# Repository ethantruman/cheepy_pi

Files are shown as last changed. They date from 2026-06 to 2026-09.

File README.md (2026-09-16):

# cheepy_pi

A budget-friendly, fully opensource DIY mini Cyberdeck powered by Raspberry Pi Model B, featuring a custom BQ25895+TPS61236P UPS, 3 cheap ST7789 display and audio system.

<p align="center">
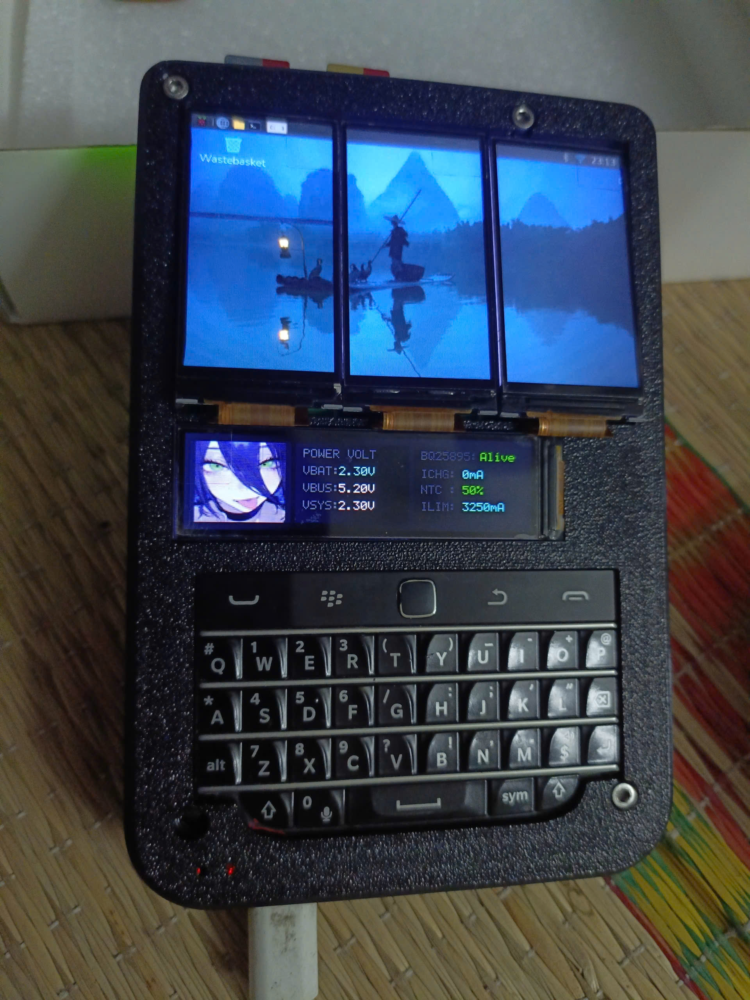
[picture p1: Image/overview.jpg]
Rear 3D View
  
  &nbsp;&nbsp;&nbsp;&nbsp;
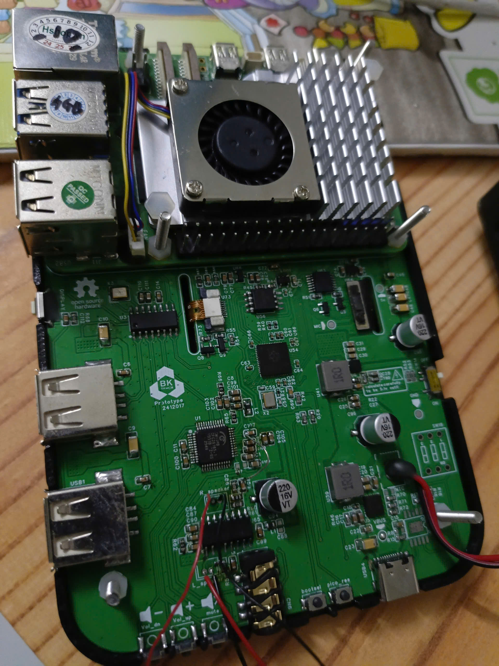
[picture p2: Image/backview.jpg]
Second View
  
</p>

## 🎬 Video Demo
https://www.instagram.com/reel/DcwldvmTygn/?stkn=MTkzajRhMjB0NHE0aw== <br>

https://www.youtube.com/shorts/QTE_7KOaZrw <br>

https://youtube.com/shorts/9MWYKX_wWpU?si=94ie98PXgPygaU7K

## Architecture
<p align="center">
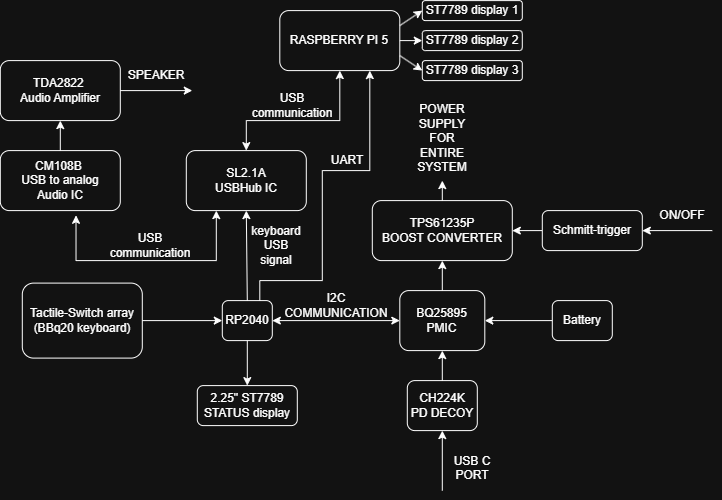
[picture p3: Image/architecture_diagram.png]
  
</p>

## Features
* **Processor:** Powered by Raspberry Pi Model B.
* **Power System:** Custom UPS utilizing BQ25895 + TPS61236P. It integrates a **CH220K** fast-charging sink controller at the input to negotiate up to a **12V input voltage** from Type-C PD charger, significantly boosting input power and enabling faster charging/stable high-load operation when plugged in.
* **Display System:** 
  * Triple (3x) low-cost ST7789 1.9" main screens.
  * An extra 2.25" ST7789 display dedicated to monitoring and displaying real-time battery status, independently managed by an onboard RP2040 microcontroller.
* **Input:** Integrated classic Blackberry Q20 keyboard, also driven and managed by the RP2040 to act as a custom USB HID device.

* **Audio:** Integrated audio system.
  
##  Current Status & Testing
* **Hardware Status:** The project is currently in the prototype stage. I am waiting for the PCBs and components to arrive for soldering, hardware debugging, and error verification. Updates will be posted as soon as testing is complete!
<p align="center">
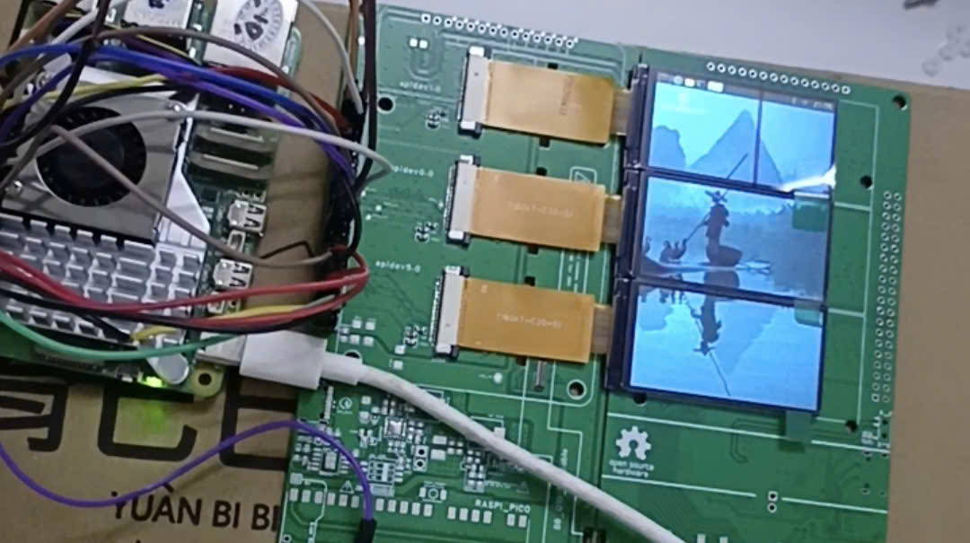
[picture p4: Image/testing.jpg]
Testing
  
</p>

* **Software/Driver Notice:** 
  The current driver for the triple (3x) ST7789 display system **only supports the latest Raspberry Pi OS** and other Linux distributions utilizing the ́**Wayland** display server protocol. Traditional X11/Xorg environments are not supported.
  
* **Update 31/7/2026:**
  * I’ve tested the display system and it works great! I pushed the SPI clock speed up to 80 MHz, and it still runs smoothly, delivering a solid 60 FPS experience.
  * Still, I'm struggling with testing the keyboard system because of soldering tiny components by hand. I'm also still writing the firmware for it. I'll update as soon as I can!
  <p align="center">
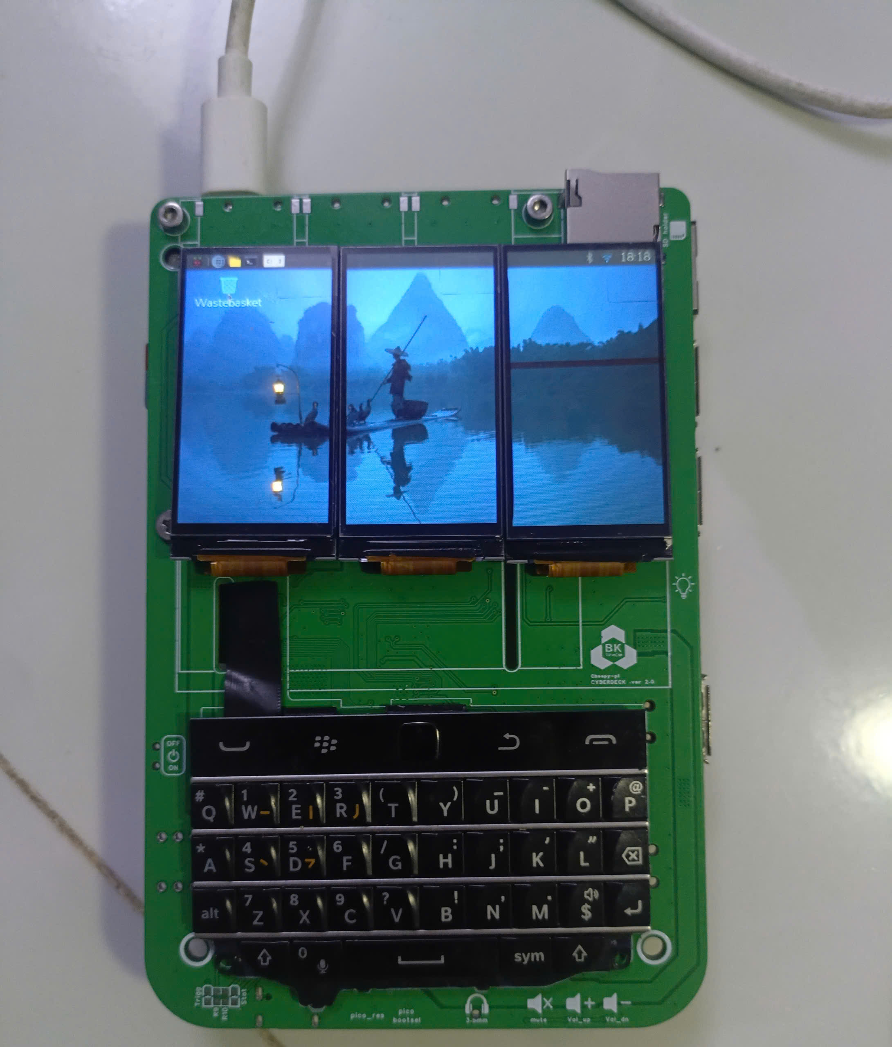
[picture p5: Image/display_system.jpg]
  
  </p>
* **Update 2/8/2026:**
  * I wrote firmware for an RP2040 system to drive 4th ST7789V 2.25" display and it worked perfectly! I'm still planning to develop more interesting features, such as displaying GIFs, animations, and dashboards. To do this, I use a Python script to convert images to the exact aspect ratio and RGB565 color format. For now, the python code is still a bit stupid and single-purpose, so it needs more work. I'll update the RP2040 firmware and Python converter code once I perfected them (NAH, usable is just enough for upload to you haha!!!!).
  * The firmware for rp2040 system to control bbq20 keyboard worked, still it's  not stable. I'm struggling with trackpad i2c communication, so i made a simple version of mouse using the A W D S to move the cursor (just a temporary workaround, I'll soon find out how the i2c trackpad work btw).
  * I'm trying my best to finish this little guy as fast as i can!!
  <p align="center">
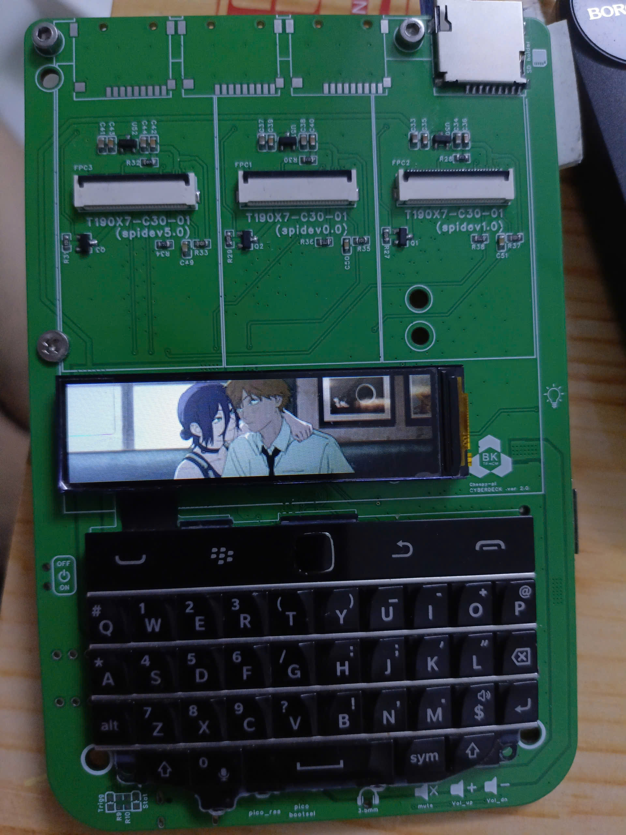
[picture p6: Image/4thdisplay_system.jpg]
  
  </p>
* **Update 7/8/2026:**
* Today I finished soldering the entire power system. I tested it with a VOM and the BQ25895 behaved normally, but the TPS61236P outputted 5.7V. Luckily, I hadn't connected my Raspberry Pi 5 yet, so it's safe.
I found the issue: the feedback resistor divider (I used 390k/91k). After re-checking the TPS61236P datasheet, it looks like the feedback ratio needs to be around 3 to 3.1. I'll update you with the results tomorrow after I buy some new resistors. Hope my pi won't be fry

* **Update 7/8/2026:**
* I finally designed and 3D-printed the upper case. Now it looks much cleaner and fantastically nice. But during the installation process, I realized that the connector to the Pi makes installing tricky and unreliable. So I'm considering using a header and jumper wires instead of this tiny connector in version 3.0. Still, I will continue to stick with this version as a workaround just to find some "hardware and mechanical bugs". Now I'm stress-testing it.
  <p align="center">
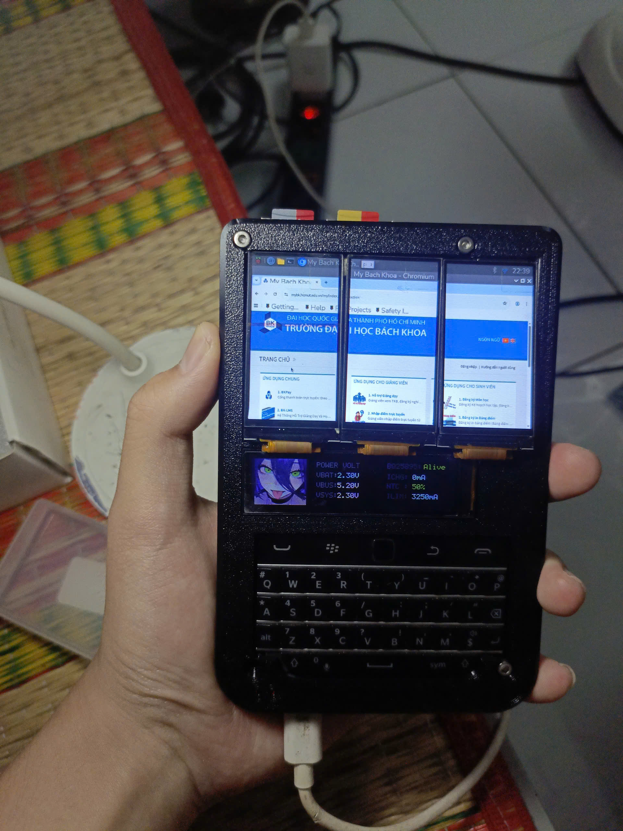
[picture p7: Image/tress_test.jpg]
  
  </p>

* **Update 16/9/2026:**
* Version 3.0 of the PCB has arrived! So, why v3.0, and what’s new? This version promises to simplify the tricky assembly steps, lower production costs, and deliver much more stable performance. I’ll complete the soldering phase and share an update soon. Right now, v3.0 might lack the fancy silkscreen icons since I prioritized performance and efficiency first,but that’s only temporary. Once testing is complete, the final version will look amazing!.
  <p align="center">
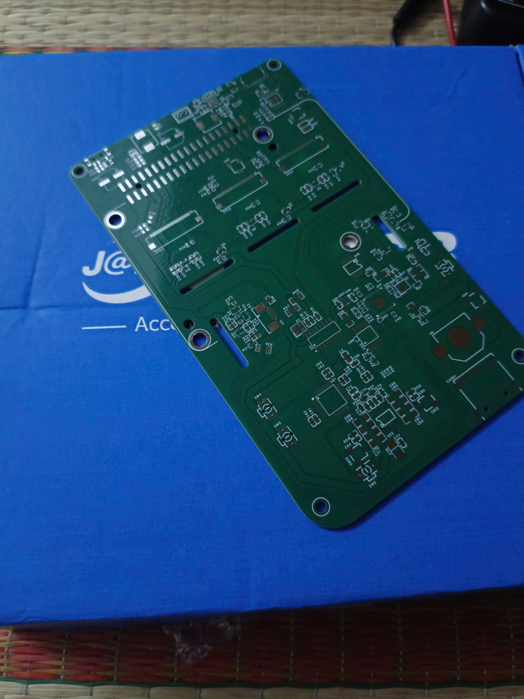
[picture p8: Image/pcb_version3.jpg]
  
  </p>

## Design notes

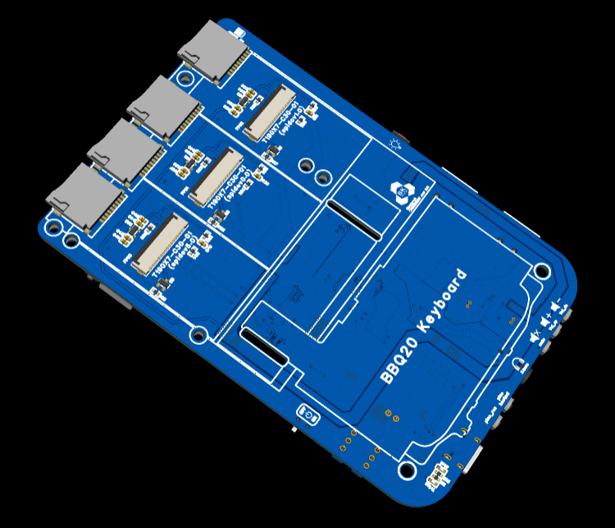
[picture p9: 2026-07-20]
Image/front3dView.png

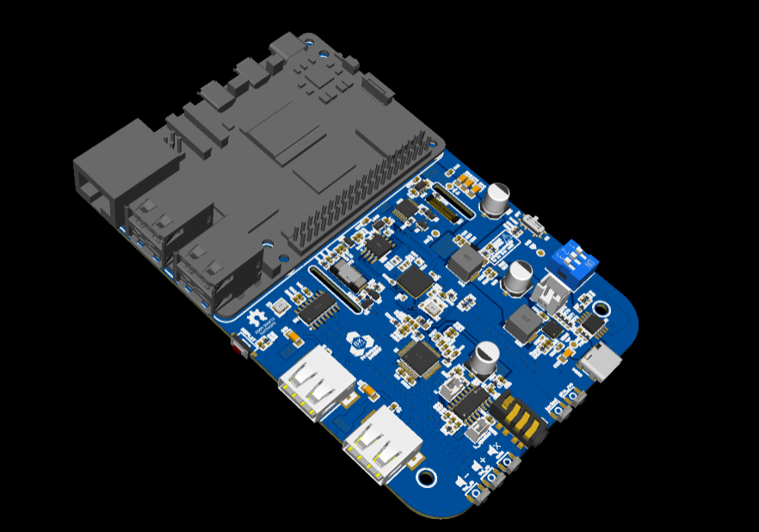
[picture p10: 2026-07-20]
Image/rear3dView.png

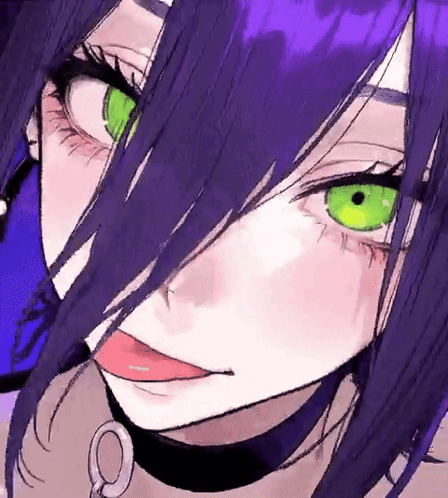
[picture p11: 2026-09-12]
RP2040_firmware/keyboard_rtos/output_frames/reze_frame_005.png

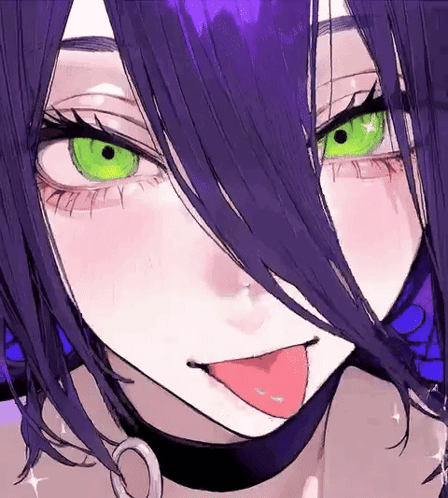
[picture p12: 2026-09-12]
RP2040_firmware/keyboard_rtos/output_frames/reze_frame_001.png

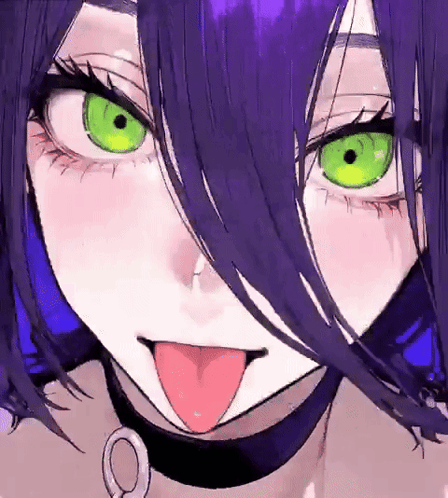
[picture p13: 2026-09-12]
RP2040_firmware/keyboard_rtos/reze_bleh/reze_frame_004.png

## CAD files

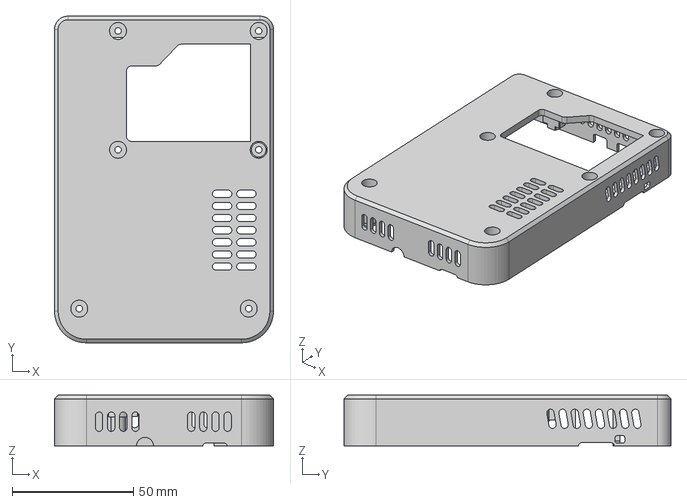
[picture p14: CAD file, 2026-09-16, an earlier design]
Old_version/3dPrinting_enclosure/bottom_cheepy_pi.step
90.3 x 134.7 x 20.9 mm

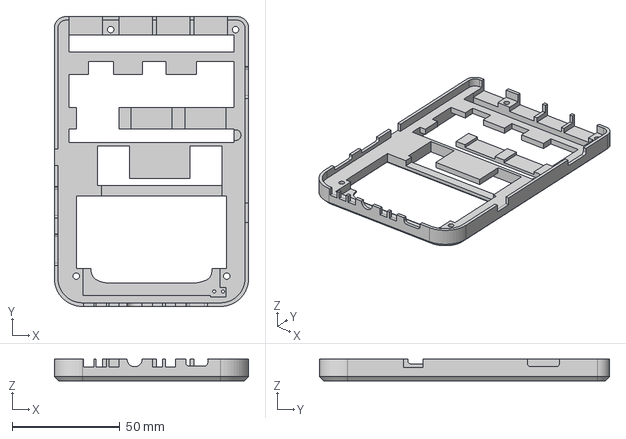
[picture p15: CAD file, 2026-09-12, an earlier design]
Old_version/3dPrinting_enclosure/upper_enclosure.step
90.3 x 134.7 x 10.1 mm

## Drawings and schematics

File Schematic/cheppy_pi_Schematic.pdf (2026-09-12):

GND A1B12 VBUS A4B9 CC1 A5 DP1 A6 DN1 A7 SBU1 A8 CC2 B5 DP2 B6 DN2 B7 SBU2 B8 VBUS B4A9 GND B1A12 SHELL 1

# XIN 16 XOUT 15 VDD18 14 VDD33 13 GND 12 VDD5 11 DP 10 DM 9

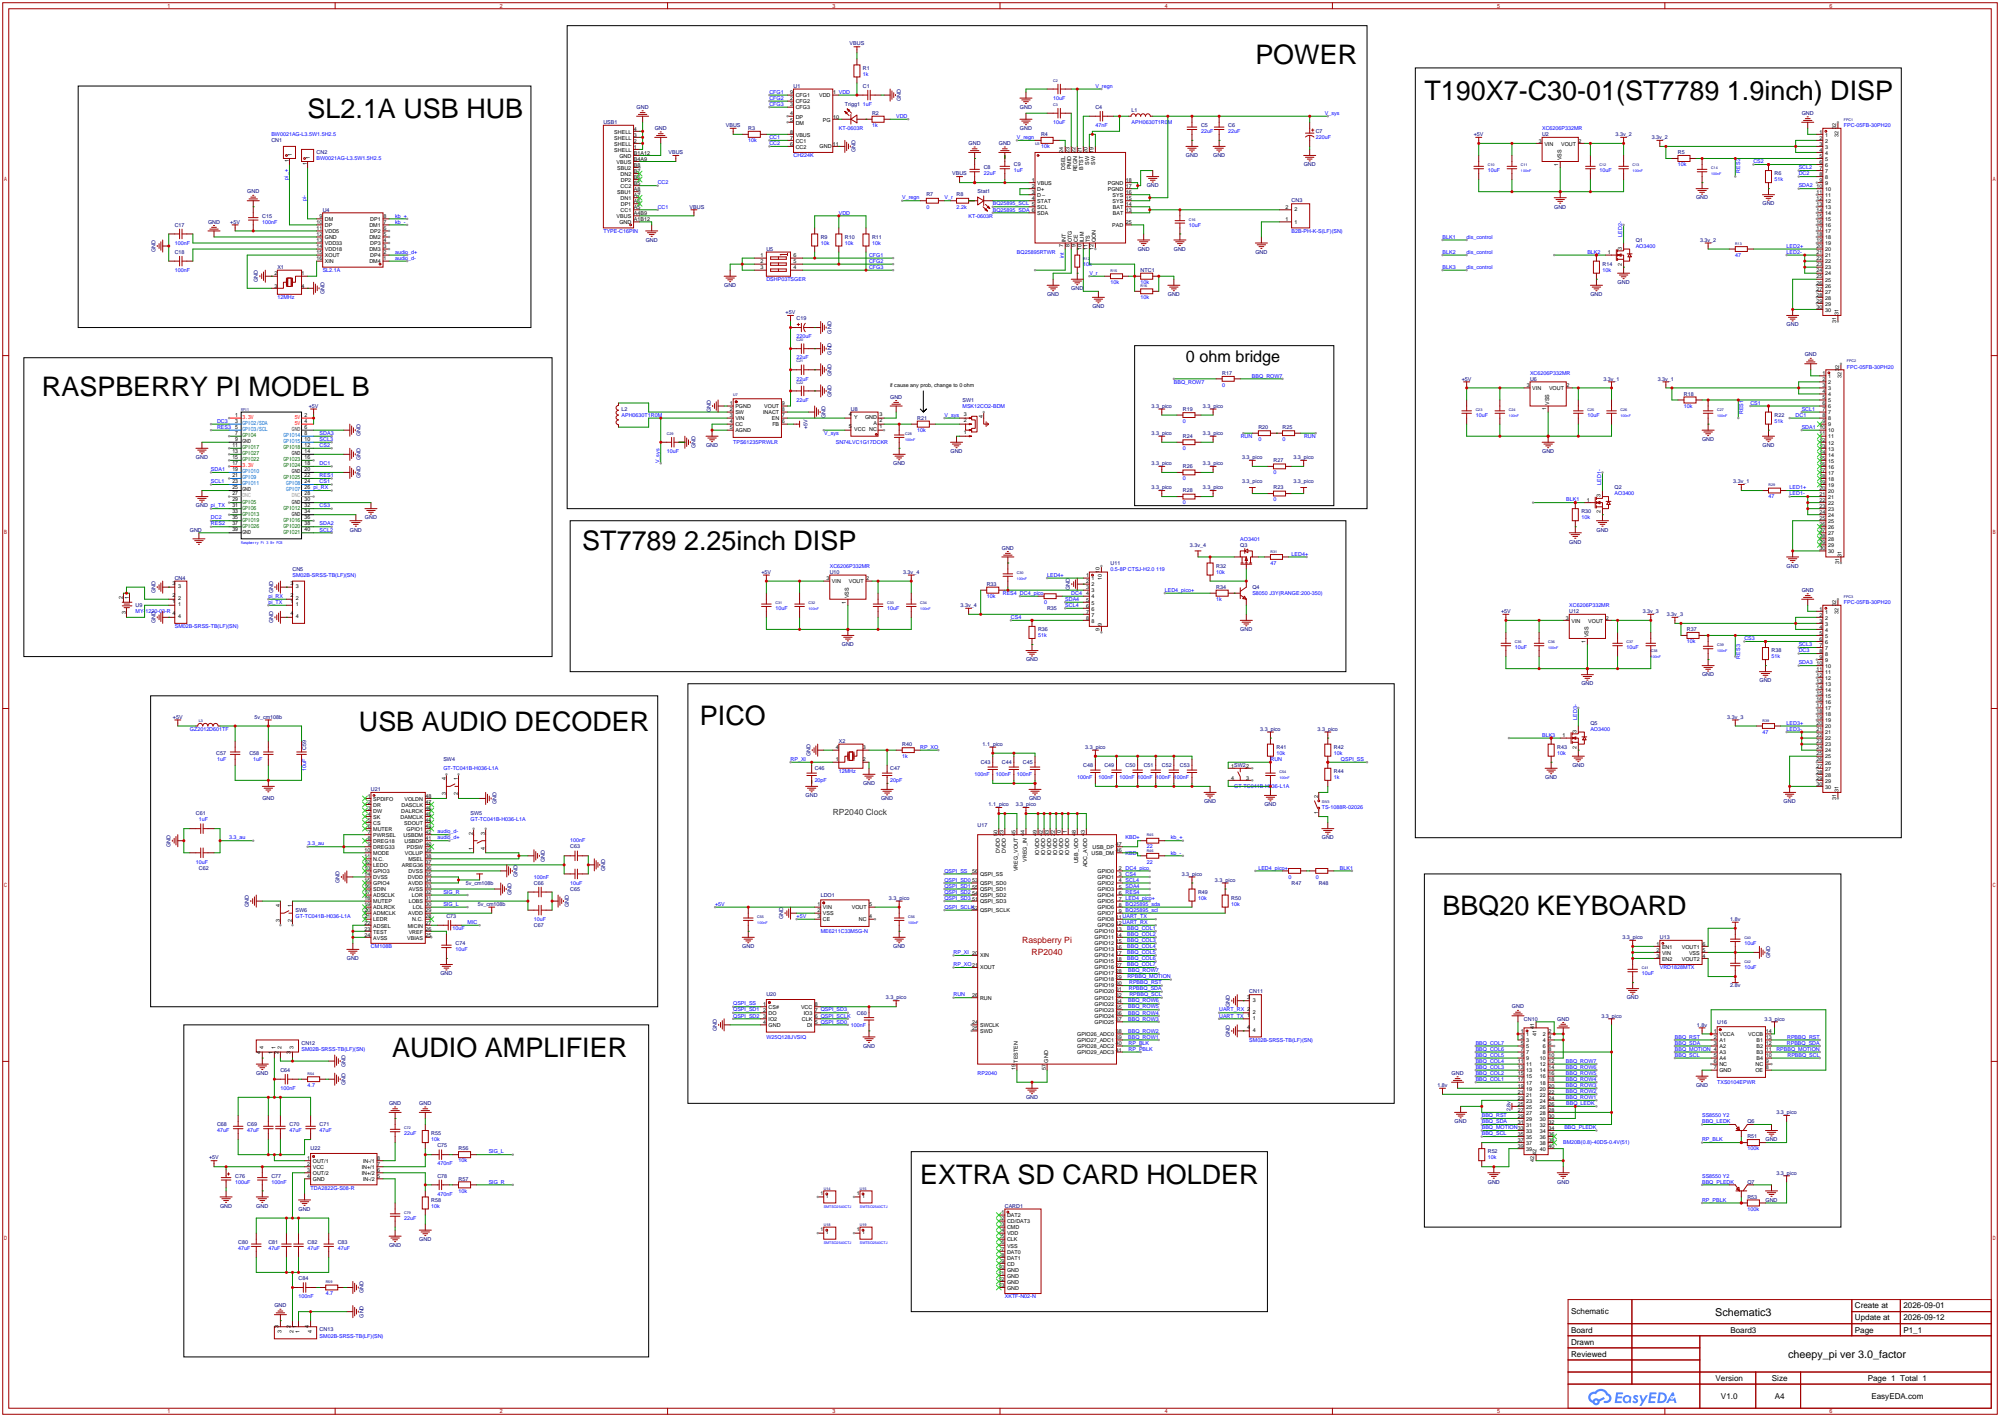
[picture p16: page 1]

if cause any prob, change to 0 ohm
GND

SM02B-SRSS-TB(LF)(SN)

EXTRA SD CARD HOLDER

Schematic | Schematic3 | Create at | 2026-09-01

Update at | 2026-09-12

Board | Board3 | Page | P1_1
Drawn | | cheepy_pi ver 3.0_factor
Reviewed

Version | Size | Page 1 Total 1
V1.0 | A4 | EasyEDA.com

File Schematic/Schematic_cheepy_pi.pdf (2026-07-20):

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

# XIN 16 XOUT 15 VDD18 14 VDD33 13 GND 12 VDD5 11 DP 10 DM 9

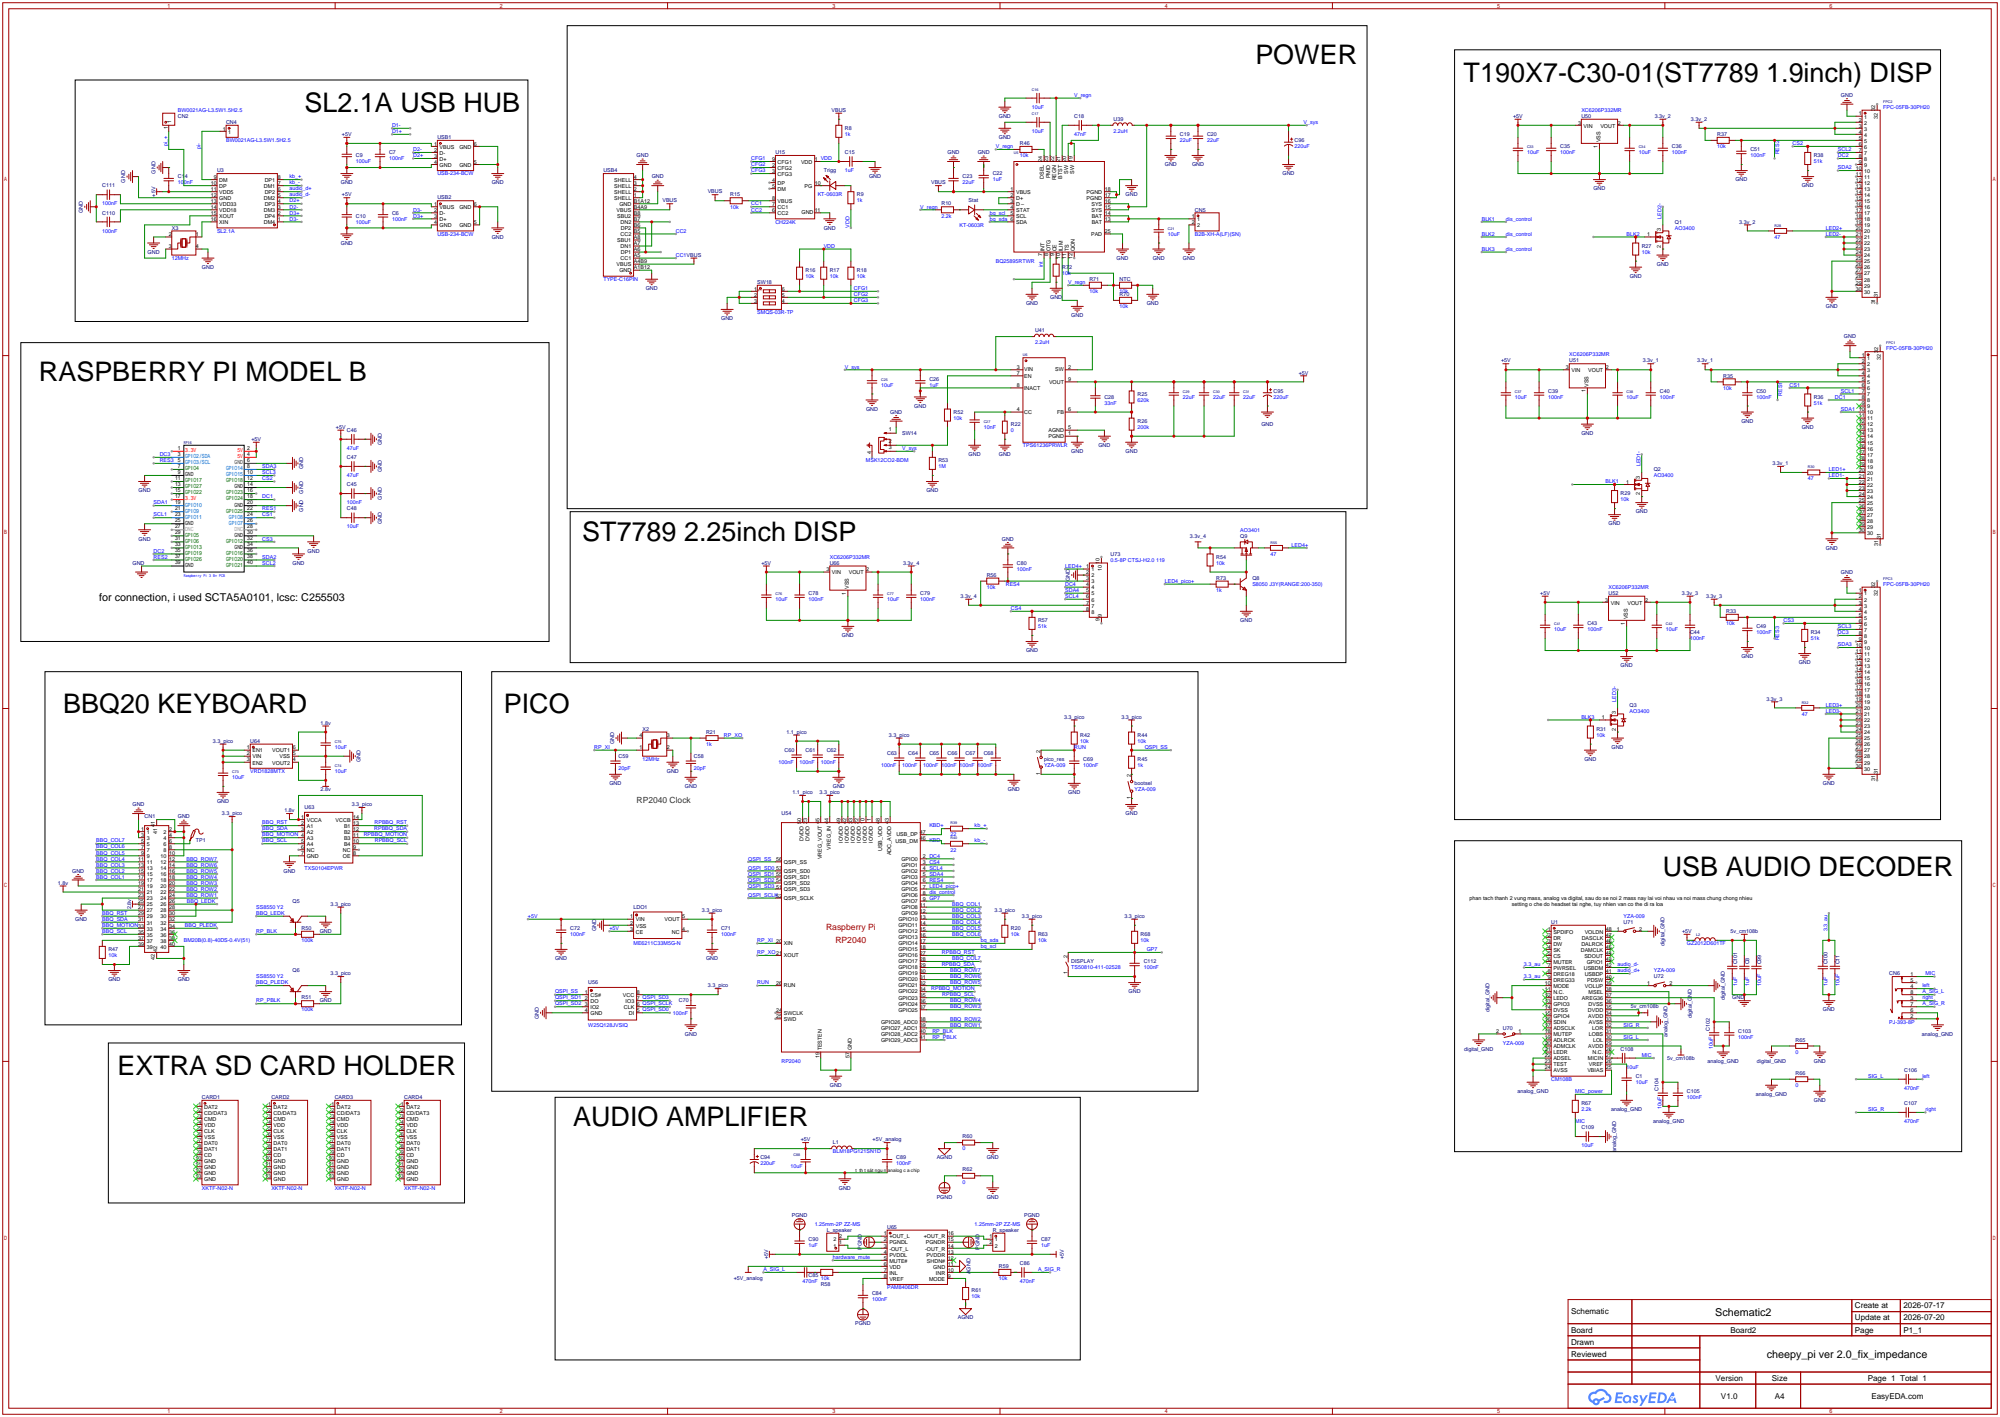
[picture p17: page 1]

GND GND

for connection, i used SCTA5A0101, lcsc: C255503

phan tach thanh 2 vung mass, analog va digital, sau do se noi 2 mass nay lai voi nhau va noi mass chung chong nhieu

setting o che do headset tai nghe, tuy nhien van co the di ra loa

EXTRA SD CARD HOLDER

Schematic | Schematic2 | Create at | 2026-07-17

Update at | 2026-07-20

Board | Board2 | Page | P1_1
Drawn | | cheepy_pi ver 2.0_fix_impedance
Reviewed

Version | Size | Page 1 Total 1
V1.0 | A4 | EasyEDA.com

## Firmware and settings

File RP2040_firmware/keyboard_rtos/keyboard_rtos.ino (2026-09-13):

#include <Arduino.h>
#define __FREERTOS 1 
#include <FreeRTOS.h>

#include <task.h>
#include <semphr.h>
#include <queue.h>
#include <timers.h>

#include <Keyboard.h>
#include <Mouse.h>
#include <avr/pgmspace.h>
#include <SPI.h>
#include <Wire.h>
#include "st7789_2.25.h"
#include "image_data.h"
#include"keyboard_MAT.h"
#include"HW_def_for_ver3.h"

// cần thêm cái switch sang gõ số ok
//thêm watchdog bq25895 ok
//thêm tab để câu hình bq25895

//mouse speed
#define MOUSE_SPEED 5

//phải có mutex bảo vệ mấy cái này
volatile float g_vbat = 0, g_vsys = 0, g_vbus = 0, g_ntcPct = 0;
volatile int g_ichg = 0, g_batPercent = 0;
volatile int g_iInLim = 0; 
volatile int g_iccLim = 0;
volatile uint8_t g_chgStat = 0; 
volatile uint8_t g_vbusStat = 0; 
volatile uint8_t g_faultStat = 0;

volatile bool isAlive = 0;

TaskHandle_t hTrackpadTask = NULL;
TaskHandle_t hKeypadTask   = NULL;
TaskHandle_t hPowerTask    = NULL;
TaskHandle_t hDisplayTask  = NULL;
TaskHandle_t hBackLightTask = NULL;

TFTDriver tft;

volatile uint8_t dashboard_page = 1;
volatile bool sym_detected = false;
volatile bool disp_ctrl = true;

void i2c_init(){
  Wire1.setSDA(I2C_SDA_PIN_bq);
  Wire1.setSCL(I2C_SCL_PIN_bq);
  Wire1.begin();

  Wire.setSDA(PIN_TRACKPAD_SDA);
  Wire.setSCL(PIN_TRACKPAD_SCL);
  Wire.begin();
}

uint8_t readBQRegister(uint8_t reg) {
  Wire1.beginTransmission(BQ25895_ADDR);
  Wire1.write(reg);
  Wire1.endTransmission(false);
  Wire1.requestFrom((uint8_t)BQ25895_ADDR, (uint8_t)1);
  return Wire1.available() ? Wire1.read() : 0;
}

void writeBQRegister(uint8_t reg, uint8_t val) {
  Wire1.beginTransmission(BQ25895_ADDR);
  Wire1.write(reg);
  Wire1.write(val);
  Wire1.endTransmission();
}

void initBQ25895() {
  uint8_t reg02 = readBQRegister(0x02);
  reg02 |= 0xC0; 
  writeBQRegister(0x02, reg02);
}

bool check_bq25895_alive() {

  // 2. Gửi tín hiệu kiểm tra (ACK) đến địa chỉ BQ25895_ADDR (0x6A)
  Wire1.beginTransmission(BQ25895_ADDR);
  uint8_t error = Wire1.endTransmission();

  // Đơn vị phản hồi: error == 0 nghĩa là chip phản hồi thành công (ACK)
  if (error != 0) {
    return false; // Chip không phản hồi (chết hoặc hỏng đường truyền)
  }
  return true;
}

void resetBQ25895Watchdog() {
  uint8_t reg01 = readBQRegister(0x01);
  reg01 |= (1 << 6); // Set bit 6 (WATCHDOG_RESET) lên 1
  writeBQRegister(0x01, reg01);
}

// Khai báo handle cho Timer ở đầu file
TimerHandle_t xBacklightTimer = NULL;

// Callback hàm này sẽ TỰ ĐỘNG CHẠY khi HẾT 30 giây không bấm phím
void vBacklightTimerCallback(TimerHandle_t xTimer) {
    disp_ctrl = false;
    digitalWrite(backlight_control_pin, LOW); // Tắt đèn nền
}

void trackpadMotionISR() {
  BaseType_t xHigherPriorityTaskWoken = pdFALSE;
  // Bắn tín hiệu Notification trực tiếp để đánh thức hTrackpadTask ngay lập tức
  if (hTrackpadTask != NULL) {
    vTaskNotifyGiveFromISR(hTrackpadTask, &xHigherPriorityTaskWoken);
    portYIELD_FROM_ISR(xHigherPriorityTaskWoken);
  }
}

void vTaskTrackpad(void *pvParameters) {
  for (;;) {
    // Task sẽ bị chặn (Block) hoàn toàn ở đây cho đến khi ISR gửi tín hiệu
      ulTaskNotifyTake(pdTRUE, portMAX_DELAY);

      Wire.beginTransmission(TRACKPAD_I2C_ADDR);
      Wire.write(REG_MOTION);
      Wire.endTransmission(false);
      Wire.requestFrom(TRACKPAD_I2C_ADDR, 1);
      if (Wire.available()) Wire.read();

      Wire.beginTransmission(TRACKPAD_I2C_ADDR);
      Wire.write(0x03);
      Wire.endTransmission(false);
      Wire.requestFrom(TRACKPAD_I2C_ADDR, 1);
      int8_t deltaX = Wire.available() ? (int8_t)Wire.read() : 0;

      Wire.beginTransmission(TRACKPAD_I2C_ADDR);
      Wire.write(0x04);
      Wire.endTransmission(false);
      Wire.requestFrom(TRACKPAD_I2C_ADDR, 1);
      int8_t deltaY = Wire.available() ? (int8_t)Wire.read() : 0;

      if (deltaX == -32 && deltaY == -32) { deltaX = 0; deltaY = 0; }

      bool isScrollPressed = (digitalRead(rowPins[2]) == LOW);
      if (deltaX != 0 || deltaY != 0) {
        if (isScrollPressed) {
          Mouse.move(0, 0, -deltaY / 4);
        } else {
          Mouse.move(-deltaX, deltaY);
        }
      }
    
  }
}

void vTaskPower(void *pvParameters) {
  TickType_t xLastWakeTime = xTaskGetTickCount();

  for (;;) {

      // Kiểm tra BQ Alive
      isAlive=check_bq25895_alive();

      if (isAlive) {
        resetBQ25895Watchdog();

        uint8_t reg00 = readBQRegister(0x00);
        g_iInLim = 100 + ((reg00 & 0x3F) * 50);

        uint8_t reg04 = readBQRegister(0x04);
        g_iccLim = (reg04 & 0x7F) * 64;

        uint8_t reg0E = readBQRegister(0x0E);
        g_vbat = 2.304 + ((reg0E & 0x7F) * 0.020);

        uint8_t reg0F = readBQRegister(0x0F);
        g_vsys = 2.304 + ((reg0F & 0x7F) * 0.020);

        uint8_t reg11 = readBQRegister(0x11);
        g_vbus = 2.600 + ((reg11 & 0x7F) * 0.100);

        uint8_t reg12 = readBQRegister(0x12);
        g_ichg = (reg12 & 0x7F) * 50;

        uint8_t reg10 = readBQRegister(0x10);
        g_ntcPct = 21.0 + ((reg10 & 0x7F) * 0.465);

        uint8_t reg0B = readBQRegister(0x0B);
        g_vbusStat = (reg0B >> 5) & 0x07;
        g_chgStat  = (reg0B >> 3) & 0x03;

        g_faultStat = readBQRegister(0x0C);

      }


    // Nhờ vTaskDelayUntil, Task sẽ chạy ĐÚNG 1000ms một lần chuẩn xác
    vTaskDelayUntil(&xLastWakeTime, pdMS_TO_TICKS(1000));
  }
}

void vTaskKeypad(void *pvParameters) {
  bool lastState[7][7] = {false};

  for (;;) {
    for (int c = 0; c < 7; c++) {
      digitalWrite(colPins[c], LOW);
      delayMicroseconds(5);

      for (int r = 0; r < 7; r++) {
        bool isPressed = (digitalRead(rowPins[r]) == LOW);

        if (isPressed && !lastState[r][c]) {

          // --- LOGIC ĐÈN NỀN MỚI ---
          // 1. Nếu màn hình đang tắt, bật lại ngay
          if (!disp_ctrl) {
            disp_ctrl = true;
            digitalWrite(backlight_control_pin, HIGH);
          }
          // 2. Restart/Reset lại bộ đếm 30s của Timer
          if (xBacklightTimer != NULL) {
            xTimerReset(xBacklightTimer, 0);
          }
          // --------------------------

          if (r == 2 && c == 1) {
            dashboard_page = (dashboard_page >= 2) ? 1 : dashboard_page + 1;
          }
          if (r == 5 && c == 4) sym_detected = !sym_detected;

          uint16_t keycode = pgm_read_word(sym_detected?(&(key_Mat[r][c])):(&(key_Mat_num[r][c])));
          if (keycode != 0xFFFF) {
            if (keycode == 0xE001) Mouse.press(MOUSE_LEFT);
            else if (keycode == 0xE002) Mouse.press(MOUSE_RIGHT);
            else Keyboard.press((uint8_t)keycode);
          }
          lastState[r][c] = true;
        } 
        else if (!isPressed && lastState[r][c]) {
          uint16_t keycode = pgm_read_word(sym_detected?(&(key_Mat[r][c])):(&(key_Mat_num[r][c])));
          if (keycode != 0xFFFF) {
            if (keycode == 0xE001) Mouse.release(MOUSE_LEFT);
            else if (keycode == 0xE002) Mouse.release(MOUSE_RIGHT);
            else Keyboard.release((uint8_t)keycode);
          }
          lastState[r][c] = false;
        }
      }
      digitalWrite(colPins[c], HIGH);
    }
    // Quét phím xong nghỉ 2ms để chống rung phím và nhường CPU
    vTaskDelay(pdMS_TO_TICKS(2));
  }
}

void drawDashboardLayout1() {
  tft.fillScreen(BG_DARK);
  tft.fillRect(4, 6, 79, 64, CARD_BG);
  tft.fillRect(87, 6, 93, 64, CARD_BG);
  tft.drawString(93, 10, "POWER VOLT", TEXT_GRAY, CARD_BG, 1);
  tft.drawString(93, 24, "VBAT: ", TEXT_GRAY, CARD_BG, 1);
  tft.drawString(93, 38, "VBUS: ", TEXT_GRAY, CARD_BG, 1);
  tft.drawString(93, 52, "VSYS: ", TEXT_GRAY, CARD_BG, 1);

  tft.fillRect(184, 6, 96, 64, CARD_BG);
  tft.drawString(190, 25, "ICHG:", TEXT_GRAY, CARD_BG, 1);
  tft.drawString(190, 38, "NTC :", TEXT_GRAY, CARD_BG, 1);

  tft.fillRect(190, 10, 84, 12, CARD_BG);
  tft.drawString(190, 52, "ILIM:", TEXT_GRAY, CARD_BG, 1);
  tft.drawString(190, 10, "BQ25895:", TEXT_GRAY, CARD_BG, 1);
  // thêm 1 cái để báo trạng thái phím chữ hay số.
}

void drawDashboardLayout2() {
  //nhiệm vụ của bạn
}

void vTaskDisplay(void *pvParameters) {
  uint8_t lastPage = 255; // Khởi tạo trang cũ khác biệt để vẽ layout lần đầu
  uint8_t currentFrame = 0;

  for (;;) {
    // 1. Chờ dữ liệu Pin tối đa 50ms (Đóng vai trò thay thế vTaskDelay cho toàn bộ Task)
    // Nếu có data mới -> Cập nhật pData. Nếu không có data -> Hết 50ms tự chạy tiếp code phía dưới

    // 2. Xử lý UI Trang 1
    if (dashboard_page == 1) {

      // Đổi trang: Chỉ vẽ lại khung nền layout khi vừa chuyển sang Page 1
      if (lastPage != 1) {
        lastPage = 1;
        drawDashboardLayout1();
      }

      // Cập nhật số liệu chữ lên TFT (Tần số quét 50ms rất mượt)
      char strBuf[16];

    snprintf(strBuf, sizeof(strBuf), "%.2fV", g_vbat);
    tft.drawString(122, 24, strBuf, ACCENT_CYAN, CARD_BG, 1);

    snprintf(strBuf, sizeof(strBuf), "%.2fV", g_vbus);
    tft.drawString(122, 38, strBuf, TEXT_WHITE, CARD_BG, 1);

    snprintf(strBuf, sizeof(strBuf), "%.2fV", g_vsys);
    tft.drawString(122, 52, strBuf, TEXT_WHITE, CARD_BG, 1);

    snprintf(strBuf, sizeof(strBuf), "%dmA", g_ichg);
    tft.drawString(225, 25, strBuf, ACCENT_CYAN, CARD_BG, 1);

    snprintf(strBuf, sizeof(strBuf), "%.0f%%", g_ntcPct);
    tft.drawString(225, 38, strBuf, ACCENT_GREEN, CARD_BG, 1);

    // --- HIỂN THỊ ILIM THAY CHO THANH % PIN ---
    snprintf(strBuf, sizeof(strBuf), "%dmA ", g_iInLim); // Thêm khoảng trắng cuối để xóa ký tự dư
    tft.drawString(225, 52, strBuf, ACCENT_CYAN, CARD_BG, 1);

      if (isAlive) {
        tft.drawString(240, 10, "Alive", ACCENT_GREEN, CARD_BG, 1);
      } else {
        tft.drawString(240, 10, "Dead   ", ACCENT_RED, CARD_BG, 1);
      }

      // Xử lý Animation Ảnh dạng State Machine (KHÔNG DÙNG VÒNG LẶP FOR!)
      // Mỗi vòng lặp Task (~50ms) chỉ vẽ đúng 1 Frame ảnh rồi nhả CPU ngay
      if (TOTAL_IMAGES > 0) {
        const uint16_t* current_img = (const uint16_t*) pgm_read_ptr(&(all_images[currentFrame]));
        tft.pushImage(8, 6, IMAGE_WIDTH, IMAGE_HEIGHT, current_img);

        // Tăng frame cho lần lặp sau
        currentFrame = (currentFrame + 1) % TOTAL_IMAGES;
      }

    } 
    // 3. Xử lý UI các Trang khác (Trang 2, Trang 3...)
    else if(dashboard_page == 2) {
      // RESET lại trang để khi quay về Page 1 sẽ tự vẽ lại layout
      if (lastPage == 1) {
        lastPage = dashboard_page;
        currentFrame = 0;
      }
      
      // Viết code vẽ các Page khác ở đây (nhiệm vụ của bạn)

    }
    vTaskDelay(pdMS_TO_TICKS(10));
  }
}

void setup() {
  Keyboard.begin();
  Mouse.begin();

  pinMode(PIN_TRACKPAD_MOTION, INPUT_PULLUP);
  pinMode(backlight_control_pin, OUTPUT);      

  if(disp_ctrl){
    digitalWrite(backlight_control_pin, HIGH);
  }   // Xuất tín hiệu mức cao (3.3V)
  else{digitalWrite(backlight_control_pin, LOW);}

  // Pin Config
  for (int i = 0; i < 7; i++) pinMode(rowPins[i], INPUT_PULLUP);
  for (int j = 0; j < 7; j++) {
    pinMode(colPins[j], OUTPUT);
    digitalWrite(colPins[j], HIGH);
  }
  pinMode(PIN_TRACKPAD_MOTION, INPUT_PULLUP);

  i2c_init();
  initBQ25895();

  attachInterrupt(digitalPinToInterrupt(PIN_TRACKPAD_MOTION), trackpadMotionISR, FALLING);

// --- TẠO SOFTWARE TIMER 30 GIÂY ---
  // pdFALSE = One-shot timer (chỉ chạy 1 lần khi kích hoạt)
  xBacklightTimer = xTimerCreate("BacklightTimer", 
                                 pdMS_TO_TICKS(30000), 
                                 pdFALSE, 
                                 (void *)0, 
                                 vBacklightTimerCallback);

  if (xBacklightTimer != NULL) {
    xTimerStart(xBacklightTimer, 0); // Kích hoạt timer ngay từ đầu
  }

// Tạo Task gắn cố định vào CORE 0 (Dùng (1 << 0))
xTaskCreateAffinitySet(vTaskTrackpad, "TrackpadTask", 2048, NULL, 4, (1 << 0), &hTrackpadTask);
xTaskCreateAffinitySet(vTaskKeypad,   "KeypadTask",   2048, NULL, 3, (1 << 0), &hKeypadTask);
xTaskCreateAffinitySet(vTaskPower,    "PowerTask",    2048, NULL, 1, (1 << 0), &hPowerTask);

}

void loop() {
  // Khi chạy RTOS, hàm loop() được bỏ trống
  vTaskDelete(NULL); 
}

void setup1() {
  tft.init();
  analogWrite(5, 16);
  drawDashboardLayout1();
  // Tạo Task gắn cố định vào CORE 1 (Dùng (1 << 1))
  xTaskCreateAffinitySet(vTaskDisplay,  "DisplayTask",  4096, NULL, 2, (1 << 1), &hDisplayTask);
}

void loop1() {
  // Khi chạy RTOS, hàm loop() được bỏ trống
  vTaskDelete(NULL); 
}

//scp "keyboard_rtos.ino.uf2" pi@192.168.137.87:/media/pi/RPI-RP2/

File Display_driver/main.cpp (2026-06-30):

#define TFT_SWRESET   0x01
#define TFT_SLPOUT    0x11
#define TFT_COLMOD    0x3A
#define TFT_MADCTL    0x36
#define TFT_CASET     0x2A
#define TFT_RASET     0x2B
#define TFT_RAMWR     0x2C
#define TFT_DISPON    0x29
#define TFT_DISPOFF   0x28
#define TFT_INVON     0x21
#define TFT_INVOFF    0x20

#include <iostream>
#include <vector>
#include <cstdint>
#include <cstring>
#include <cerrno>
#include <fcntl.h>
#include <unistd.h>
#include <sys/ioctl.h>
#include <linux/spi/spidev.h>
#include <gpiod.h> // libgpiod v2 headers
#include <cstdio>
#include <memory>
#include <iomanip>
#include <thread>
#include <mutex>
#include <atomic>
#include <chrono>    // Cho std::chrono::milliseconds
#include <algorithm> // Cho std::swap

//đây là một dự án driver cho các đời rpi dùng màn hình spi st7789v, yêu cầu dùng libgpiod v2 và spidev để điều khiển màn hình. Yêu cầu tương thích với mọi đời rpi, chỉ cần thay đổi /dev/gpiochip4 thành /dev/gpiochip0 nếu dùng pi cũ.

class ST7789; // <--- Dòng này gọi là Forward Declaration

class ST7789 {
private:
    int spi_fd;
    struct gpiod_chip *chip;
    struct gpiod_line_settings *settings;
    struct gpiod_line_config *line_cfg;
    struct gpiod_request_config *req_cfg;
    struct gpiod_line_request *request;

    unsigned int dc_off, rst_off;

    void send_command(uint8_t cmd) {
        gpiod_line_request_set_value(request, dc_off, GPIOD_LINE_VALUE_INACTIVE); // DC low
        //usleep(10); // DC setup time (10µs)
        // thử bỏ usleep để tăng tốc độ, nếu gặp lỗi hiển thị thì hãy bật lại
        ssize_t ret = write(spi_fd, &cmd, 1);
        if (ret != 1) {
            std::cerr << "Error: Failed to send command 0x" << std::hex << (int)cmd << std::endl;
        }
    }

    void send_data(uint8_t data) {
        gpiod_line_request_set_value(request, dc_off, GPIOD_LINE_VALUE_ACTIVE); // DC high
        //usleep(10); // DC setup time (10µs)
        // thử bỏ usleep để tăng tốc độ, nếu gặp lỗi hiển thị thì hãy bật lại
        ssize_t ret = write(spi_fd, &data, 1);
        if (ret != 1) {         
            std::cerr << "Error: Failed to send data 0x" << std::hex << (int)data << std::endl;
        }
    }

    void send_command_data(const uint8_t* data, size_t len) {
        // Hàm này gửi command và chuỗi data ngắn
        send_command(data[0]); // Gửi byte đầu tiên làm command)
        gpiod_line_request_set_value(request, dc_off, GPIOD_LINE_VALUE_ACTIVE); // DC high cho data
        usleep(10);
        if (len > 1) {
             ssize_t ret = write(spi_fd, &data[1], len - 1);
            if (ret != (ssize_t)(len - 1)) {
                std::cerr << "Error: When send_command_data";
            }
        }
    }
public:
    void set_window(uint16_t x0, uint16_t y0, uint16_t x1, uint16_t y1) {
        uint16_t x_end = x0 + x1 - 1;
        uint16_t y_end = y0 + y1 - 1;

        uint8_t col_cmd[] = {0x2A, (uint8_t)(x0 >> 8), (uint8_t)(x0 & 0xFF),
                             (uint8_t)(x_end >> 8), (uint8_t)(x_end & 0xFF)};
        send_command_data(col_cmd, 5);

        // ILI9341 set row address (0x2B): SP[15:0] EP[15:0] - inclusive
        uint8_t row_cmd[] = {0x2B, (uint8_t)(y0 >> 8), (uint8_t)(y0 & 0xFF),
                             (uint8_t)(y_end >> 8), (uint8_t)(y_end & 0xFF)};
        send_command_data(row_cmd, 5);
    }


    //Hàm init cho màn
    ST7789(const char* spi_dev, const char* chip_path, unsigned int dc, unsigned int rst)
        : spi_fd(-1), chip(nullptr), settings(nullptr), line_cfg(nullptr),
          req_cfg(nullptr), request(nullptr), dc_off(dc), rst_off(rst) {

        // 1. SPI Setup
        spi_fd = open(spi_dev, O_RDWR);
        if (spi_fd < 0) {
            std::cerr << "Error: Cannot open SPI device: " << spi_dev
                      << " (" << std::strerror(errno) << ")" << std::endl;
            return;
        }

        // Set SPI Mode 0 (CPOL=0, CPHA=0) - required by ILI9341
        uint8_t mode = SPI_MODE_0;
        if (ioctl(spi_fd, SPI_IOC_WR_MODE, &mode) < 0) {
            std::cerr << "Error: Failed to set SPI mode (" << std::strerror(errno) << ")" << std::endl;
            close(spi_fd);
            spi_fd = -1;
            return;
        }

        // Set MSB-first (0) 
        uint8_t lsb = 0;
        if (ioctl(spi_fd, SPI_IOC_WR_LSB_FIRST, &lsb) < 0) {
            std::cerr << "Error: Failed to set MSB-first (" << std::strerror(errno) << ")" << std::endl;
            close(spi_fd);
            spi_fd = -1;
            return;
        }

        
        uint32_t speed = 80000000;
        if (ioctl(spi_fd, SPI_IOC_WR_MAX_SPEED_HZ, &speed) < 0) {
            std::cerr << "Error: Failed to set SPI speed (" << std::strerror(errno) << ")" << std::endl;
            close(spi_fd);
            spi_fd = -1;
            return;
        }

        // Set SPI bits per word (8-bit)
        uint8_t bits = 8;
        if (ioctl(spi_fd, SPI_IOC_WR_BITS_PER_WORD, &bits) < 0) {
            std::cerr << "Error: Failed to set bits per word (" << std::strerror(errno) << ")" << std::endl;
            close(spi_fd);
            spi_fd = -1;
            return;
        }

        // 2. libgpiod v2 Setup
        chip = gpiod_chip_open(chip_path);
        if (!chip) {
            std::cerr << "Error: Cannot open GPIO chip: " << chip_path << std::endl;
            close(spi_fd);
            spi_fd = -1;
            return;
        }

        settings = gpiod_line_settings_new();
        if (!settings) {
            std::cerr << "Error: Cannot allocate line settings" << std::endl;
            gpiod_chip_close(chip);
            chip = nullptr;
            close(spi_fd);
            spi_fd = -1;
            return;
        }
        gpiod_line_settings_set_direction(settings, GPIOD_LINE_DIRECTION_OUTPUT);

        line_cfg = gpiod_line_config_new();
        if (!line_cfg) {
            std::cerr << "Error: Cannot allocate line config" << std::endl;
            gpiod_line_settings_free(settings);
            settings = nullptr;
            gpiod_chip_close(chip);
            chip = nullptr;
            close(spi_fd);
            spi_fd = -1;
            return;
        }

        unsigned int offsets[] = {dc_off, rst_off};
        gpiod_line_config_add_line_settings(line_cfg, offsets, 2, settings);

        req_cfg = gpiod_request_config_new();
        if (!req_cfg) {
            std::cerr << "Error: Cannot allocate request config" << std::endl;
            gpiod_line_config_free(line_cfg);
            line_cfg = nullptr;
            gpiod_line_settings_free(settings);
            settings = nullptr;
            gpiod_chip_close(chip);
            chip = nullptr;
            close(spi_fd);
            spi_fd = -1;
            return;
        }
        gpiod_request_config_set_consumer(req_cfg, "ili9341_test");
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

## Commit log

2026-06-30 add gerber file
2026-07-20 Remove Raspberry Pi Zero mention from README
2026-07-21 Update power system component in README
    Updated the power system component from BQ25894 to BQ25895 for improved functionality.
2026-08-07 Add update on power system progress
    Added update on power system soldering and testing results.
2026-09-12 new version updating
    [upper_enclosure.step]
2026-09-13 add some bugs to fix later
    [HW_def_for_ver3.h, keyboard_rtos.ino]
